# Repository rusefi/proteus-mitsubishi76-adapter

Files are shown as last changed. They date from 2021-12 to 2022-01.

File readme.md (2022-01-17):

https://github.com/rusefi/rusefi and https://github.com/mck1117/proteus

76 pin

2 gen DSM
1995-1999 Mitsubishi Eclipse and Eagle Talon Turbo DSM ECU Pinouts 

v6

Lancer up to 2005?

Our document, need work
[Connector Pinout Spreadsheet, with links to wiring drawings](https://docs.google.com/spreadsheets/d/1ZlcC5cdCwjYoV-z49MNaa9zpLiu_ZYBIx5H-j0F6QpI)

Norman notes https://docs.google.com/spreadsheets/d/1ddxDElQDG0ZjSaX5fpkFeflPWwk7OCHC93gru9Ey_9U

Random sources of info

https://my.prostreetonline.com/2013/09/05/faq-1g-and-2g-dsm-ecu-pinouts/

http://www.stealth316.com/2-ecu-terminals.htm

Compatible case:

MD329098

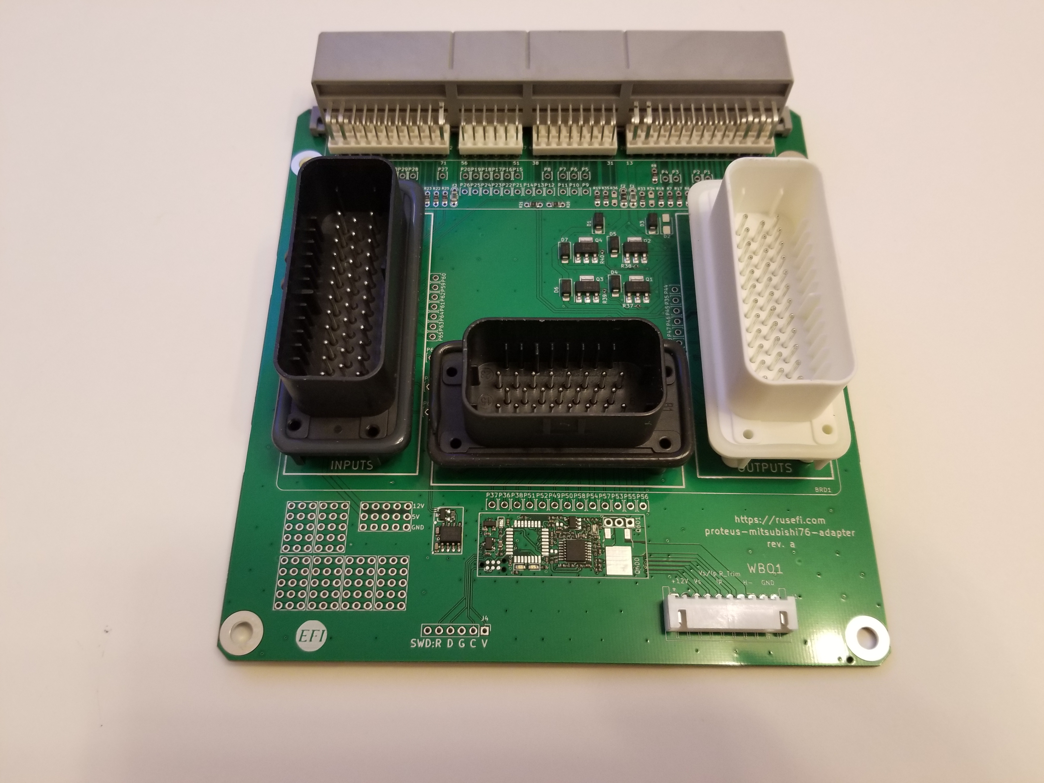
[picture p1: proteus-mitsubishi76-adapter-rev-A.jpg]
x


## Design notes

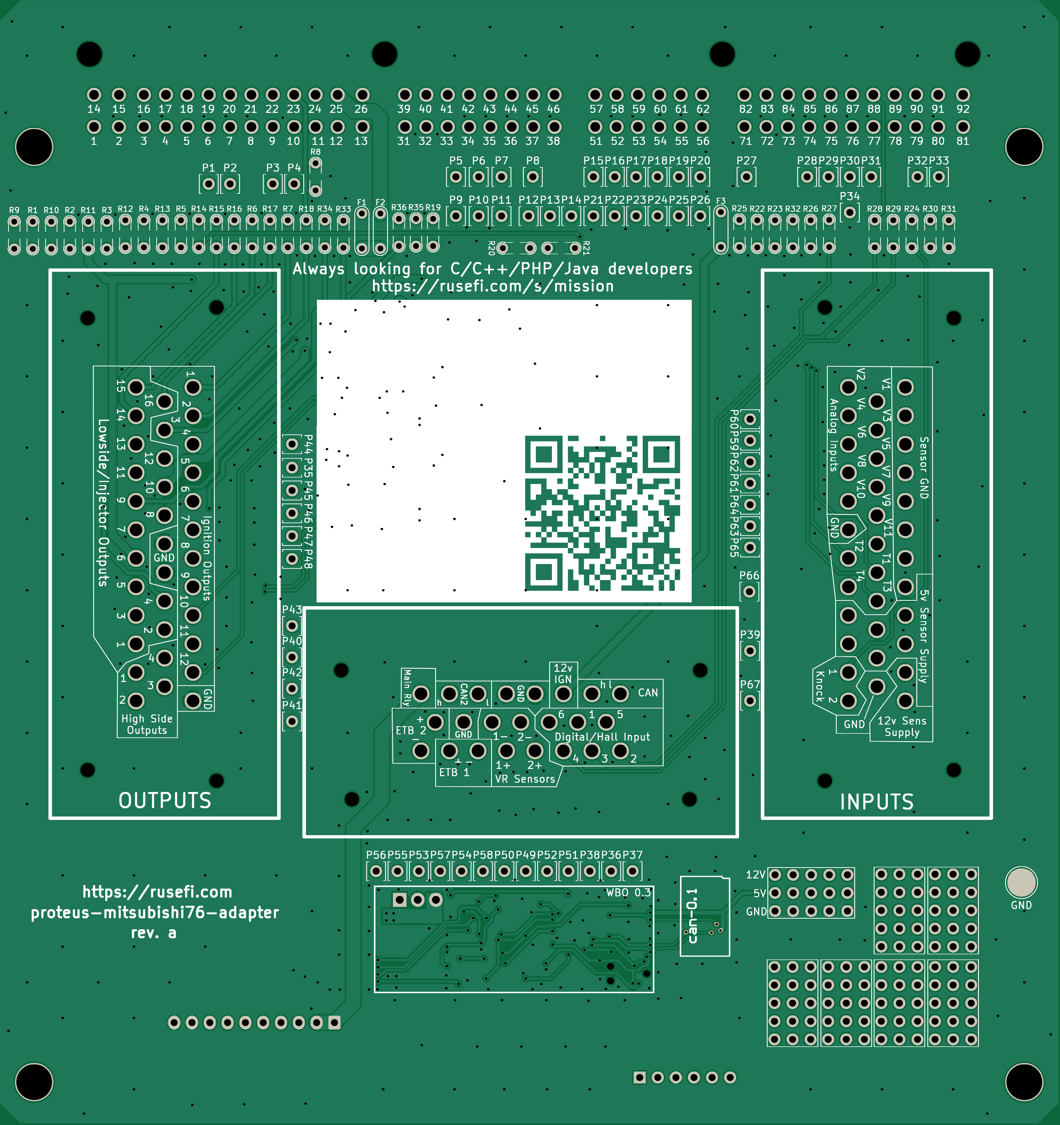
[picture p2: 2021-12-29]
proteus-mitsubishi76-adapter/boards/proteus-mitsubishi76-adapter-a/board/misc/proteus-mitsubishi76-adapter-a-bottom.png

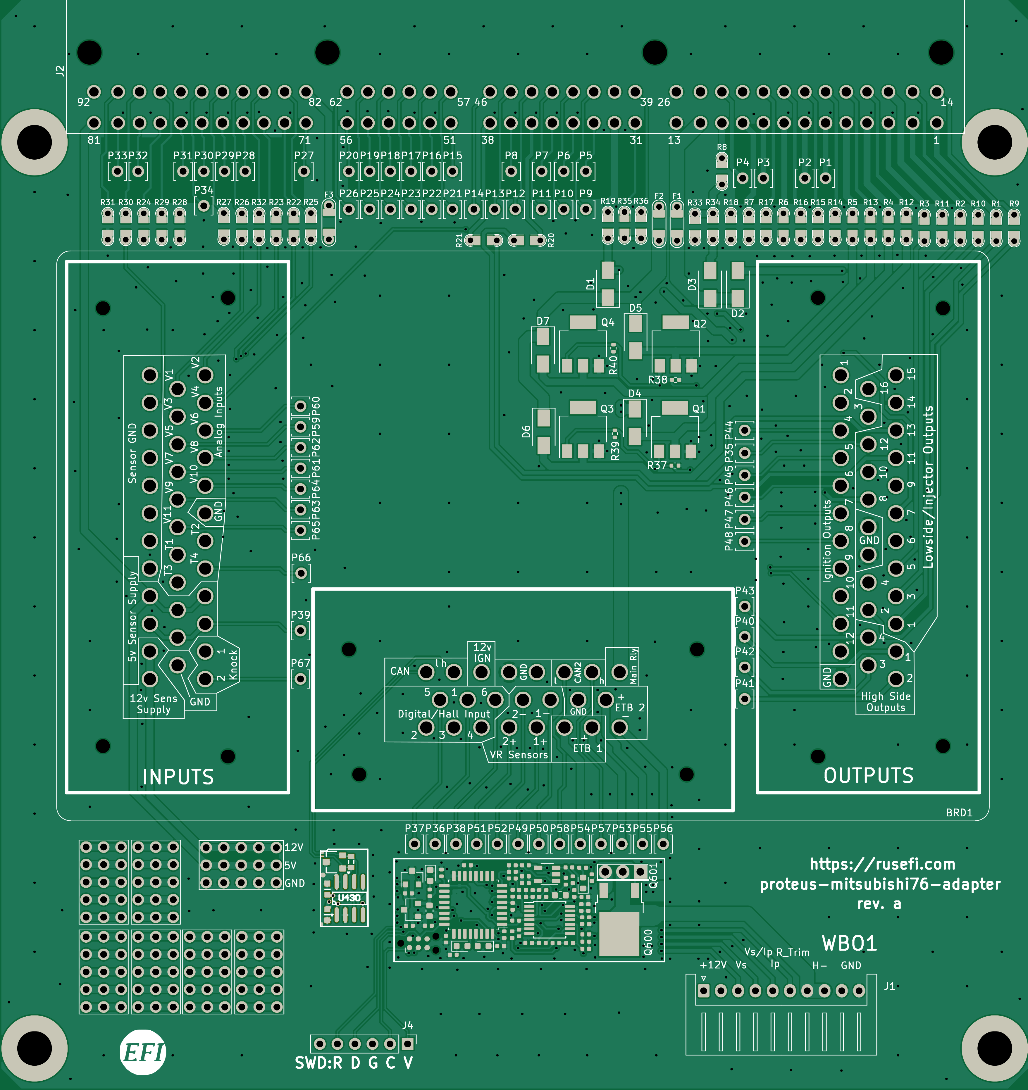
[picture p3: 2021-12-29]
proteus-mitsubishi76-adapter/boards/proteus-mitsubishi76-adapter-a/board/misc/proteus-mitsubishi76-adapter-a-top.png

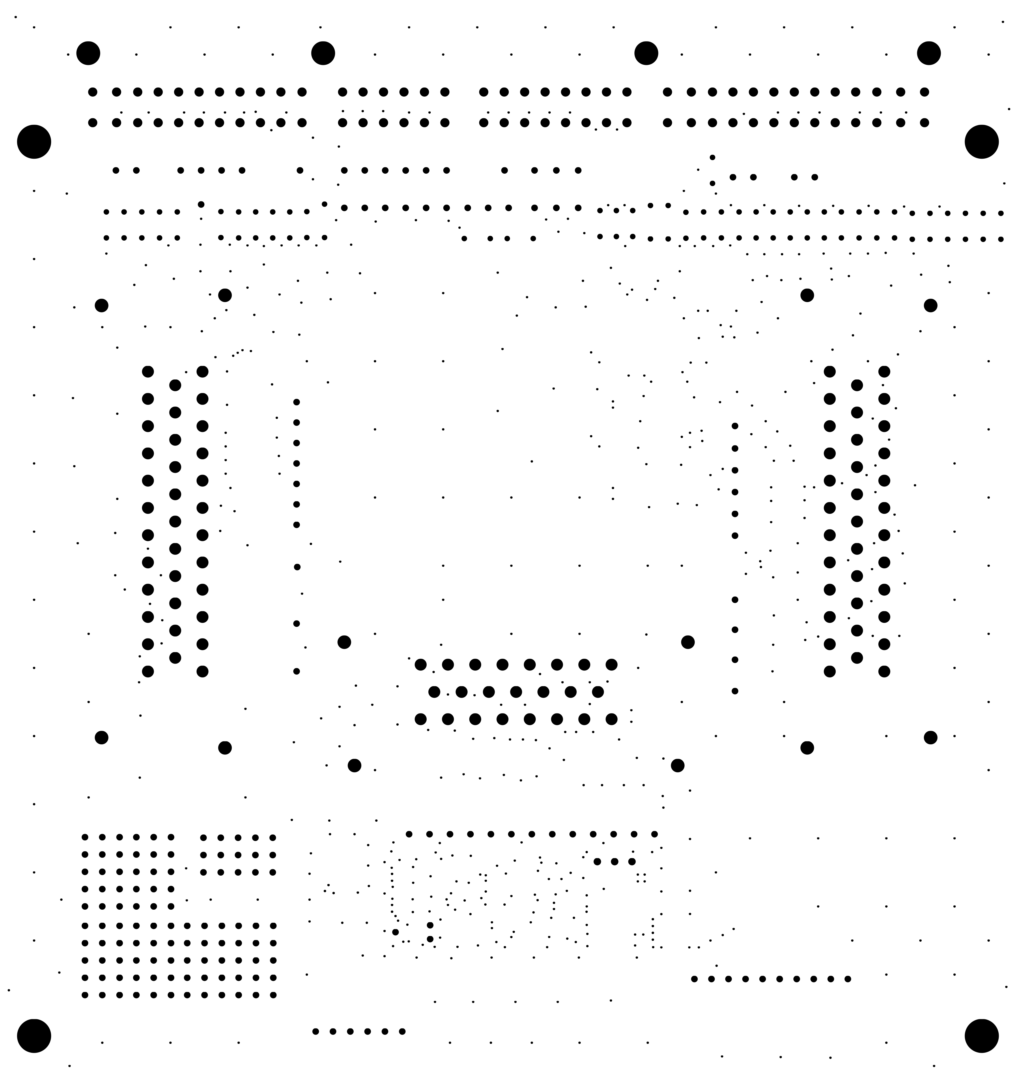
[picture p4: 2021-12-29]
proteus-mitsubishi76-adapter/boards/proteus-mitsubishi76-adapter-a/board/misc/proteus-mitsubishi76-adapter-a-outline.png

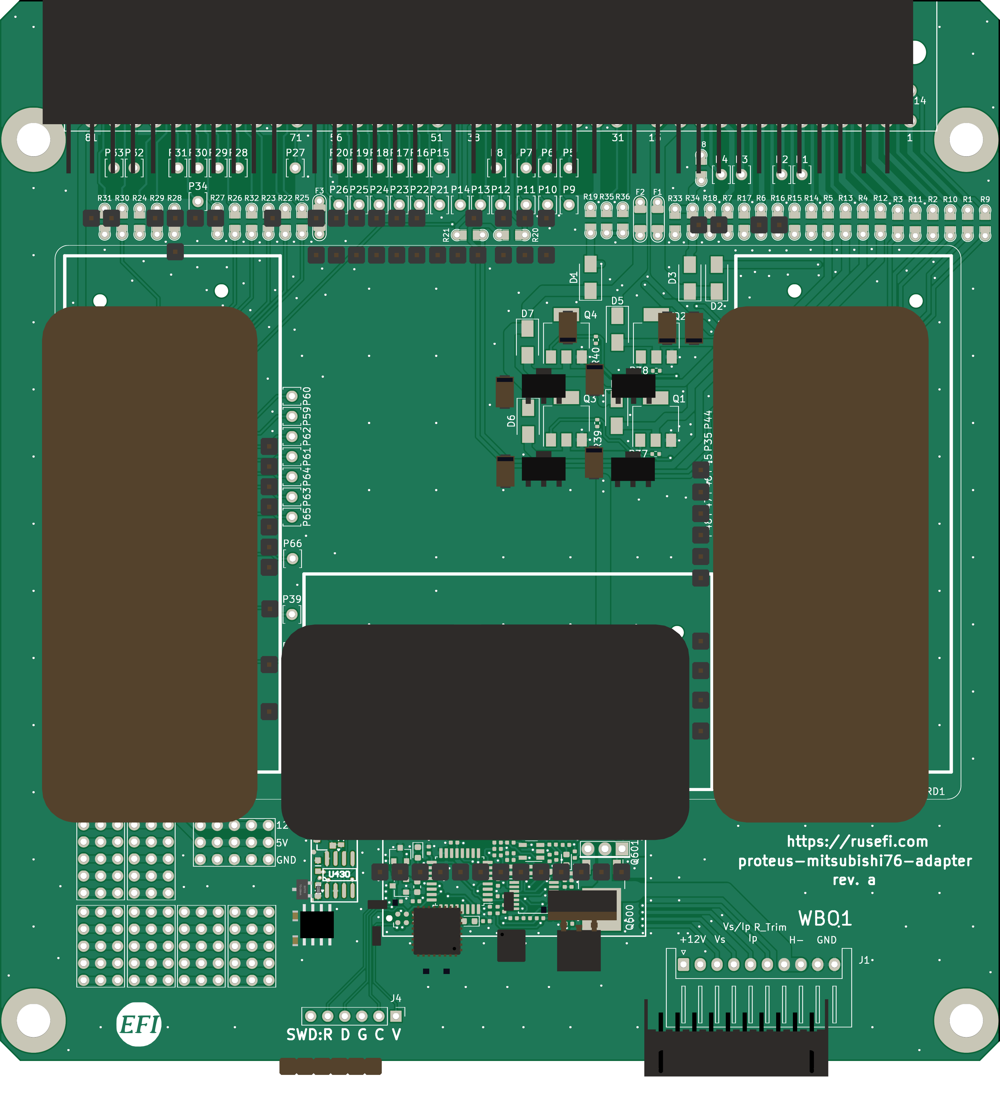
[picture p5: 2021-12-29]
proteus-mitsubishi76-adapter/boards/proteus-mitsubishi76-adapter-a/board/proteus-mitsubishi76-adapter-a.png

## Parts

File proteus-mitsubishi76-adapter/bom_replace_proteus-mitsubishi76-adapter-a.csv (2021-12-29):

#WBO low-side (D2PAK, TO220)
Q600,
Q601,
#WBO STM32
U602,
#low-side
Q1,"BSP78","SOT-223","C56914"
Q2,"BSP78","SOT-223","C56914"
Q3,"BSP78","SOT-223","C56914"
Q4,"BSP78","SOT-223","C56914"

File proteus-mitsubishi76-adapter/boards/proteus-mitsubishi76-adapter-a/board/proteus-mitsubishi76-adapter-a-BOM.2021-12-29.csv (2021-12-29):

Comment | Designator | Footprint | LCSC Part #
proteus | BRD1 | proteus
D_Schottky | D1, D3, D4, D5, D6, D7 | D_SMA | C8678
DNP | D2 | D_SMA
Fuse-Pad-Pad | F1, F3 | PAD-1206-PAD | C182446
Fuse-Pad-Pad | F2 | PAD-1206-PAD
RUSEFI_LOGO | G1 | rusefi_logo
PROTO_AREA | G2 | PROTO_AREA
PROTO_AREA | G3 | PROTO_AREA
PROTO_AREA | G4 | PROTO_AREA
PROTO_AREA | G5 | PROTO_AREA
PROTO_AREA | G6 | PROTO_AREA
PROTO_AREA | G7 | PROTO_AREA
PROTO_AREA | G8 | PROTO_AREA
MountingHole | H1 | MountingHole_5mm_Pad_TopOnly
MountingHole | H2 | MountingHole_5mm_Pad_TopOnly
MountingHole | H3 | MountingHole_5mm_Pad_TopOnly
MountingHole | H4 | MountingHole_5mm_Pad_TopOnly
XH-10AW | J1 | JST_XH_S10B-XH-A_1x10_P2.50mm_Horizontal | C14652
TE-3-178780-6 | J2 | TE-3-178780-6
Conn_01x06 | J4 | PinHeader_1x06_P2.54mm_Vertical
Conn_01x01 | J5 | TestPoint_Pad_D4.0mm
Pad | P1 | PAD-TH
Pad | P2 | PAD-TH
Pad | P3 | PAD-TH
Pad | P4 | PAD-TH
Pad | P5 | PAD-TH
Pad | P6 | PAD-TH
Pad | P7 | PAD-TH
Pad | P8 | PAD-TH
Pad | P9 | PAD-TH
Pad | P10 | PAD-TH
Pad | P11 | PAD-TH
Pad | P12 | PAD-TH
Pad | P13 | PAD-TH
Pad | P14 | PAD-TH
Pad | P15 | PAD-TH
Pad | P16 | PAD-TH
Pad | P17 | PAD-TH
Pad | P18 | PAD-TH
Pad | P19 | PAD-TH
Pad | P20 | PAD-TH
Pad | P21 | PAD-TH
Pad | P22 | PAD-TH
Pad | P23 | PAD-TH
Pad | P24 | PAD-TH
Pad | P25 | PAD-TH
Pad | P26 | PAD-TH
Pad | P27 | PAD-TH
Pad | P28 | PAD-TH
Pad | P29 | PAD-TH
Pad | P30 | PAD-TH
Pad | P31 | PAD-TH
Pad | P32 | PAD-TH
Pad | P33 | PAD-TH
Pad | P34 | PAD-TH
Pad | P35 | PAD-TH
Pad | P36 | PAD-TH
Pad | P37 | PAD-TH
Pad | P38 | PAD-TH
Pad | P39 | PAD-TH
Pad | P40 | PAD-TH
Pad | P41 | PAD-TH
Pad | P42 | PAD-TH
Pad | P43 | PAD-TH
Pad | P44 | PAD-TH
Pad | P45 | PAD-TH
Pad | P46 | PAD-TH
Pad | P47 | PAD-TH
Pad | P48 | PAD-TH
Pad | P49 | PAD-TH
Pad | P50 | PAD-TH
Pad | P51 | PAD-TH
Pad | P52 | PAD-TH
Pad | P53 | PAD-TH
Pad | P54 | PAD-TH
Pad | P55 | PAD-TH
Pad | P56 | PAD-TH
Pad | P57 | PAD-TH
Pad | P58 | PAD-TH
Pad | P59 | PAD-TH
Pad | P60 | PAD-TH
Pad | P61 | PAD-TH
Pad | P62 | PAD-TH
Pad | P63 | PAD-TH
Pad | P64 | PAD-TH
Pad | P65 | PAD-TH
Pad | P66 | PAD-TH
Pad | P67 | PAD-TH
Jumper-Pad-Pad | R1, R2, R3, R4, R5, R6, R7, R8, R9, R10, R11, R12, R13, R14, R15, R16, R17, R18, R19, R20, R21, R22, R23, R24, R25, R26, R27, R28, R29, R30, R31, R32, R33, R35 | PAD-0805-PAD | C17477
Jumper-Pad-Pad | R34 | PAD-0805-PAD
Jumper-Pad-Pad | R36 | PAD-0805-PAD
10k | R37, R38, R39, R40 | R0402 | C60489
1u | C600, C607, C609, C610, C611 | C0402 | C52923
100n | C601, C602, C605, C608, C612, C613, C614, C615 | C0402 | C1525
33n | C603 | C0402 | C1585
DNP | C604 | C0402
DNP | C606 | C0402
4.7u | C616 | C0603 | C19666
LED-RED-0603 | D600, D603 | LED-0603 | C2286
LED-GREEN-0603 | D601 | LED-0603 | C72043
LED-BLUE-0603 | D602 | LED-0603 | C72041
1k | R600, R601, R616, R617, R622, R626, R627, R628 | R0402 | C11702
68k | R602, R603 | R0402 | C36871
10k | R604, R605, R613, R614, R618, R619, R625 | R0402 | C25744
10 | R606 | R0402 | C25077
22k | R607 | R0402 | C25768
47 | R608 | R0402 | C25118
61.9 | R609 | R0603 | C23092
20k | R610, R611, R612 | R0402 | C25765
100k | R615, R621 | R0402 | C25741
27k | R620, R623 | R0402 | C25771
3.3k | R624 | R0402 | C25890
MCP6004 | U600 | TSSOP14 | C50282
AD8628 | U601 | TSOT23-5 | C29309
REF3033 | U603 | SOT-23 | C36658
XC6206P332MR | U604 | SOT-23 | C5446
100n | C430, C431 | C0603 | C14663
PESD1CAN | D430 | SOT-23 | C343993
120 | R430 | R0603 | C22787
TJA1051T/3/1J | U430 | SO8 | C38695
BSP78 | Q1, Q2, Q3, Q4 | SOT-223 | C56914

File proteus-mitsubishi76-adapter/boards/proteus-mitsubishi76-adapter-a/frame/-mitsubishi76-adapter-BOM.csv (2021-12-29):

Comment | Designator | Footprint | LCSC Part #
proteus | BRD1 | proteus
D_Schottky | D1 | D_SMA | C8678
DNP | D2 | D_SMA
D_Schottky | D3 | D_SMA | C8678
D_Schottky | D4 | D_SMA | C8678
D_Schottky | D5 | D_SMA | C8678
D_Schottky | D6 | D_SMA | C8678
D_Schottky | D7 | D_SMA | C8678
Fuse-Pad-Pad | F1 | PAD-1206-PAD | C182446
Fuse-Pad-Pad | F2 | PAD-1206-PAD
Fuse-Pad-Pad | F3 | PAD-1206-PAD | C182446
RUSEFI_LOGO | G1 | rusefi_logo
PROTO_AREA | G2 | PROTO_AREA
PROTO_AREA | G3 | PROTO_AREA
PROTO_AREA | G4 | PROTO_AREA
PROTO_AREA | G5 | PROTO_AREA
PROTO_AREA | G6 | PROTO_AREA
PROTO_AREA | G7 | PROTO_AREA
PROTO_AREA | G8 | PROTO_AREA
MountingHole | H1 | MountingHole_5mm_Pad_TopOnly
MountingHole | H2 | MountingHole_5mm_Pad_TopOnly
MountingHole | H3 | MountingHole_5mm_Pad_TopOnly
MountingHole | H4 | MountingHole_5mm_Pad_TopOnly
XH-10AW | J1 | JST_XH_S10B-XH-A_1x10_P2.50mm_Horizontal | C14652
TE-3-178780-6 | J2 | TE-3-178780-6
Conn_01x06 | J4 | PinHeader_1x06_P2.54mm_Vertical
Conn_01x01 | J5 | TestPoint_Pad_D4.0mm
Module:wbo/0.3 | M1 | wbo
Module:can/0.1 | M2 | can
Pad | P1 | PAD-TH
Pad | P2 | PAD-TH
Pad | P3 | PAD-TH
Pad | P4 | PAD-TH
Pad | P5 | PAD-TH
Pad | P6 | PAD-TH
Pad | P7 | PAD-TH
Pad | P8 | PAD-TH
Pad | P9 | PAD-TH
Pad | P10 | PAD-TH
Pad | P11 | PAD-TH
Pad | P12 | PAD-TH
Pad | P13 | PAD-TH
Pad | P14 | PAD-TH
Pad | P15 | PAD-TH
Pad | P16 | PAD-TH
Pad | P17 | PAD-TH
Pad | P18 | PAD-TH
Pad | P19 | PAD-TH
Pad | P20 | PAD-TH
Pad | P21 | PAD-TH
Pad | P22 | PAD-TH
Pad | P23 | PAD-TH
Pad | P24 | PAD-TH
Pad | P25 | PAD-TH
Pad | P26 | PAD-TH
Pad | P27 | PAD-TH
Pad | P28 | PAD-TH
Pad | P29 | PAD-TH
Pad | P30 | PAD-TH
Pad | P31 | PAD-TH
Pad | P32 | PAD-TH
Pad | P33 | PAD-TH
Pad | P34 | PAD-TH
Pad | P35 | PAD-TH
Pad | P36 | PAD-TH
Pad | P37 | PAD-TH
Pad | P38 | PAD-TH
Pad | P39 | PAD-TH
Pad | P40 | PAD-TH
Pad | P41 | PAD-TH
Pad | P42 | PAD-TH
Pad | P43 | PAD-TH
Pad | P44 | PAD-TH
Pad | P45 | PAD-TH
Pad | P46 | PAD-TH
Pad | P47 | PAD-TH
Pad | P48 | PAD-TH
Pad | P49 | PAD-TH
Pad | P50 | PAD-TH
Pad | P51 | PAD-TH
Pad | P52 | PAD-TH
Pad | P53 | PAD-TH
Pad | P54 | PAD-TH
Pad | P55 | PAD-TH
Pad | P56 | PAD-TH
Pad | P57 | PAD-TH
Pad | P58 | PAD-TH
Pad | P59 | PAD-TH
Pad | P60 | PAD-TH
Pad | P61 | PAD-TH
Pad | P62 | PAD-TH
Pad | P63 | PAD-TH
Pad | P64 | PAD-TH
Pad | P65 | PAD-TH
Pad | P66 | PAD-TH
Pad | P67 | PAD-TH
AUIPS2041LTR | Q1 | SOT-223 | C113610
AUIPS2041LTR | Q2 | SOT-223 | C113610
AUIPS2041LTR | Q3 | SOT-223 | C113610
AUIPS2041LTR | Q4 | SOT-223 | C113610
Jumper-Pad-Pad | R1 | PAD-0805-PAD | C17477
Jumper-Pad-Pad | R2 | PAD-0805-PAD | C17477
Jumper-Pad-Pad | R3 | PAD-0805-PAD | C17477
Jumper-Pad-Pad | R4 | PAD-0805-PAD | C17477
Jumper-Pad-Pad | R5 | PAD-0805-PAD | C17477
Jumper-Pad-Pad | R6 | PAD-0805-PAD | C17477
Jumper-Pad-Pad | R7 | PAD-0805-PAD | C17477
Jumper-Pad-Pad | R8 | PAD-0805-PAD | C17477
Jumper-Pad-Pad | R9 | PAD-0805-PAD | C17477
Jumper-Pad-Pad | R10 | PAD-0805-PAD | C17477
Jumper-Pad-Pad | R11 | PAD-0805-PAD | C17477
Jumper-Pad-Pad | R12 | PAD-0805-PAD | C17477
Jumper-Pad-Pad | R13 | PAD-0805-PAD | C17477
Jumper-Pad-Pad | R14 | PAD-0805-PAD | C17477
Jumper-Pad-Pad | R15 | PAD-0805-PAD | C17477
Jumper-Pad-Pad | R16 | PAD-0805-PAD | C17477
Jumper-Pad-Pad | R17 | PAD-0805-PAD | C17477
Jumper-Pad-Pad | R18 | PAD-0805-PAD | C17477
Jumper-Pad-Pad | R19 | PAD-0805-PAD | C17477
Jumper-Pad-Pad | R20 | PAD-0805-PAD | C17477
Jumper-Pad-Pad | R21 | PAD-0805-PAD | C17477
Jumper-Pad-Pad | R22 | PAD-0805-PAD | C17477
Jumper-Pad-Pad | R23 | PAD-0805-PAD | C17477
Jumper-Pad-Pad | R24 | PAD-0805-PAD | C17477
Jumper-Pad-Pad | R25 | PAD-0805-PAD | C17477
Jumper-Pad-Pad | R26 | PAD-0805-PAD | C17477
Jumper-Pad-Pad | R27 | PAD-0805-PAD | C17477
Jumper-Pad-Pad | R28 | PAD-0805-PAD | C17477
Jumper-Pad-Pad | R29 | PAD-0805-PAD | C17477
Jumper-Pad-Pad | R30 | PAD-0805-PAD | C17477
Jumper-Pad-Pad | R31 | PAD-0805-PAD | C17477
Jumper-Pad-Pad | R32 | PAD-0805-PAD | C17477
Jumper-Pad-Pad | R33 | PAD-0805-PAD | C17477
Jumper-Pad-Pad | R34 | PAD-0805-PAD
Jumper-Pad-Pad | R35 | PAD-0805-PAD | C17477
Jumper-Pad-Pad | R36 | PAD-0805-PAD
10k | R37 | R0402 | C60489
10k | R38 | R0402 | C60489
10k | R39 | R0402 | C60489
10k | R40 | R0402 | C60489

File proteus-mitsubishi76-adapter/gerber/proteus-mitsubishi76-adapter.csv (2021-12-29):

Comment | Designator | Footprint | LCSC Part #
proteus | BRD1 | kicad6-libraries:proteus
D_Schottky | D1 | Diode_SMD:D_SMA | C8678
DNP | D2 | Diode_SMD:D_SMA
D_Schottky | D3 | Diode_SMD:D_SMA | C8678
D_Schottky | D4 | Diode_SMD:D_SMA | C8678
D_Schottky | D5 | Diode_SMD:D_SMA | C8678
D_Schottky | D6 | Diode_SMD:D_SMA | C8678
D_Schottky | D7 | Diode_SMD:D_SMA | C8678
Fuse-Pad-Pad | F1 | hellen-one-common:PAD-1206-PAD | C182446
Fuse-Pad-Pad | F2 | hellen-one-common:PAD-1206-PAD
Fuse-Pad-Pad | F3 | hellen-one-common:PAD-1206-PAD | C182446
RUSEFI_LOGO | G1 | kicad6-libraries:rusefi_logo
PROTO_AREA | G2 | hellen-one-common:PROTO_AREA
PROTO_AREA | G3 | hellen-one-common:PROTO_AREA
PROTO_AREA | G4 | hellen-one-common:PROTO_AREA
PROTO_AREA | G5 | hellen-one-common:PROTO_AREA
PROTO_AREA | G6 | hellen-one-common:PROTO_AREA
PROTO_AREA | G7 | hellen-one-common:PROTO_AREA
PROTO_AREA | G8 | hellen-one-common:PROTO_AREA
MountingHole | H1 | MountingHole:MountingHole_5mm_Pad_TopOnly
MountingHole | H2 | MountingHole:MountingHole_5mm_Pad_TopOnly
MountingHole | H3 | MountingHole:MountingHole_5mm_Pad_TopOnly
MountingHole | H4 | MountingHole:MountingHole_5mm_Pad_TopOnly
XH-10AW | J1 | Connector_JST:JST_XH_S10B-XH-A_1x10_P2.50mm_Horizontal | C14652
TE-3-178780-6 | J2 | kicad6-libraries:TE-3-178780-6
Conn_01x06 | J4 | Connector_PinHeader_2.54mm:PinHeader_1x06_P2.54mm_Vertical
Conn_01x01 | J5 | TestPoint:TestPoint_Pad_D4.0mm
Module-wbo-0.3 | M1 | hellen-one-wbo-0.3:wbo
Module-can-0.1 | M2 | hellen-one-can-0.1:can
Pad | P1 | hellen-one-common:PAD-TH
Pad | P2 | hellen-one-common:PAD-TH
Pad | P3 | hellen-one-common:PAD-TH
Pad | P4 | hellen-one-common:PAD-TH
Pad | P5 | hellen-one-common:PAD-TH
Pad | P6 | hellen-one-common:PAD-TH
Pad | P7 | hellen-one-common:PAD-TH
Pad | P8 | hellen-one-common:PAD-TH
Pad | P9 | hellen-one-common:PAD-TH
Pad | P10 | hellen-one-common:PAD-TH
Pad | P11 | hellen-one-common:PAD-TH
Pad | P12 | hellen-one-common:PAD-TH
Pad | P13 | hellen-one-common:PAD-TH
Pad | P14 | hellen-one-common:PAD-TH
Pad | P15 | hellen-one-common:PAD-TH
Pad | P16 | hellen-one-common:PAD-TH
Pad | P17 | hellen-one-common:PAD-TH
Pad | P18 | hellen-one-common:PAD-TH
Pad | P19 | hellen-one-common:PAD-TH
Pad | P20 | hellen-one-common:PAD-TH
Pad | P21 | hellen-one-common:PAD-TH
Pad | P22 | hellen-one-common:PAD-TH
Pad | P23 | hellen-one-common:PAD-TH
Pad | P24 | hellen-one-common:PAD-TH
Pad | P25 | hellen-one-common:PAD-TH
Pad | P26 | hellen-one-common:PAD-TH
Pad | P27 | hellen-one-common:PAD-TH
Pad | P28 | hellen-one-common:PAD-TH
Pad | P29 | hellen-one-common:PAD-TH
Pad | P30 | hellen-one-common:PAD-TH
Pad | P31 | hellen-one-common:PAD-TH
Pad | P32 | hellen-one-common:PAD-TH
Pad | P33 | hellen-one-common:PAD-TH
Pad | P34 | hellen-one-common:PAD-TH
Pad | P35 | hellen-one-common:PAD-TH
Pad | P36 | hellen-one-common:PAD-TH
Pad | P37 | hellen-one-common:PAD-TH
Pad | P38 | hellen-one-common:PAD-TH
Pad | P39 | hellen-one-common:PAD-TH
Pad | P40 | hellen-one-common:PAD-TH
Pad | P41 | hellen-one-common:PAD-TH
Pad | P42 | hellen-one-common:PAD-TH
Pad | P43 | hellen-one-common:PAD-TH
Pad | P44 | hellen-one-common:PAD-TH
Pad | P45 | hellen-one-common:PAD-TH
Pad | P46 | hellen-one-common:PAD-TH
Pad | P47 | hellen-one-common:PAD-TH
Pad | P48 | hellen-one-common:PAD-TH
Pad | P49 | hellen-one-common:PAD-TH
Pad | P50 | hellen-one-common:PAD-TH
Pad | P51 | hellen-one-common:PAD-TH
Pad | P52 | hellen-one-common:PAD-TH
Pad | P53 | hellen-one-common:PAD-TH
Pad | P54 | hellen-one-common:PAD-TH
Pad | P55 | hellen-one-common:PAD-TH
Pad | P56 | hellen-one-common:PAD-TH
Pad | P57 | hellen-one-common:PAD-TH
Pad | P58 | hellen-one-common:PAD-TH
Pad | P59 | hellen-one-common:PAD-TH
Pad | P60 | hellen-one-common:PAD-TH
Pad | P61 | hellen-one-common:PAD-TH
Pad | P62 | hellen-one-common:PAD-TH
Pad | P63 | hellen-one-common:PAD-TH
Pad | P64 | hellen-one-common:PAD-TH
Pad | P65 | hellen-one-common:PAD-TH
Pad | P66 | hellen-one-common:PAD-TH
Pad | P67 | hellen-one-common:PAD-TH
AUIPS2041LTR | Q1 | Package_TO_SOT_SMD:SOT-223 | C113610
AUIPS2041LTR | Q2 | Package_TO_SOT_SMD:SOT-223 | C113610
AUIPS2041LTR | Q3 | Package_TO_SOT_SMD:SOT-223 | C113610
AUIPS2041LTR | Q4 | Package_TO_SOT_SMD:SOT-223 | C113610
Jumper-Pad-Pad | R1 | hellen-one-common:PAD-0805-PAD | C17477
Jumper-Pad-Pad | R2 | hellen-one-common:PAD-0805-PAD | C17477
Jumper-Pad-Pad | R3 | hellen-one-common:PAD-0805-PAD | C17477
Jumper-Pad-Pad | R4 | hellen-one-common:PAD-0805-PAD | C17477
Jumper-Pad-Pad | R5 | hellen-one-common:PAD-0805-PAD | C17477
Jumper-Pad-Pad | R6 | hellen-one-common:PAD-0805-PAD | C17477
Jumper-Pad-Pad | R7 | hellen-one-common:PAD-0805-PAD | C17477
Jumper-Pad-Pad | R8 | hellen-one-common:PAD-0805-PAD | C17477
Jumper-Pad-Pad | R9 | hellen-one-common:PAD-0805-PAD | C17477
Jumper-Pad-Pad | R10 | hellen-one-common:PAD-0805-PAD | C17477
Jumper-Pad-Pad | R11 | hellen-one-common:PAD-0805-PAD | C17477
Jumper-Pad-Pad | R12 | hellen-one-common:PAD-0805-PAD | C17477
Jumper-Pad-Pad | R13 | hellen-one-common:PAD-0805-PAD | C17477
Jumper-Pad-Pad | R14 | hellen-one-common:PAD-0805-PAD | C17477
Jumper-Pad-Pad | R15 | hellen-one-common:PAD-0805-PAD | C17477
Jumper-Pad-Pad | R16 | hellen-one-common:PAD-0805-PAD | C17477
Jumper-Pad-Pad | R17 | hellen-one-common:PAD-0805-PAD | C17477
Jumper-Pad-Pad | R18 | hellen-one-common:PAD-0805-PAD | C17477
Jumper-Pad-Pad | R19 | hellen-one-common:PAD-0805-PAD | C17477
Jumper-Pad-Pad | R20 | hellen-one-common:PAD-0805-PAD | C17477
Jumper-Pad-Pad | R21 | hellen-one-common:PAD-0805-PAD | C17477
Jumper-Pad-Pad | R22 | hellen-one-common:PAD-0805-PAD | C17477
Jumper-Pad-Pad | R23 | hellen-one-common:PAD-0805-PAD | C17477
Jumper-Pad-Pad | R24 | hellen-one-common:PAD-0805-PAD | C17477
Jumper-Pad-Pad | R25 | hellen-one-common:PAD-0805-PAD | C17477
Jumper-Pad-Pad | R26 | hellen-one-common:PAD-0805-PAD | C17477
Jumper-Pad-Pad | R27 | hellen-one-common:PAD-0805-PAD | C17477
Jumper-Pad-Pad | R28 | hellen-one-common:PAD-0805-PAD | C17477
Jumper-Pad-Pad | R29 | hellen-one-common:PAD-0805-PAD | C17477
Jumper-Pad-Pad | R30 | hellen-one-common:PAD-0805-PAD | C17477
Jumper-Pad-Pad | R31 | hellen-one-common:PAD-0805-PAD | C17477
Jumper-Pad-Pad | R32 | hellen-one-common:PAD-0805-PAD | C17477
Jumper-Pad-Pad | R33 | hellen-one-common:PAD-0805-PAD | C17477
Jumper-Pad-Pad | R34 | hellen-one-common:PAD-0805-PAD
Jumper-Pad-Pad | R35 | hellen-one-common:PAD-0805-PAD | C17477
Jumper-Pad-Pad | R36 | hellen-one-common:PAD-0805-PAD
10k | R37 | Resistor_SMD:R_0402_1005Metric | C60489
10k | R38 | Resistor_SMD:R_0402_1005Metric | C60489
10k | R39 | Resistor_SMD:R_0402_1005Metric | C60489
10k | R40 | Resistor_SMD:R_0402_1005Metric | C60489

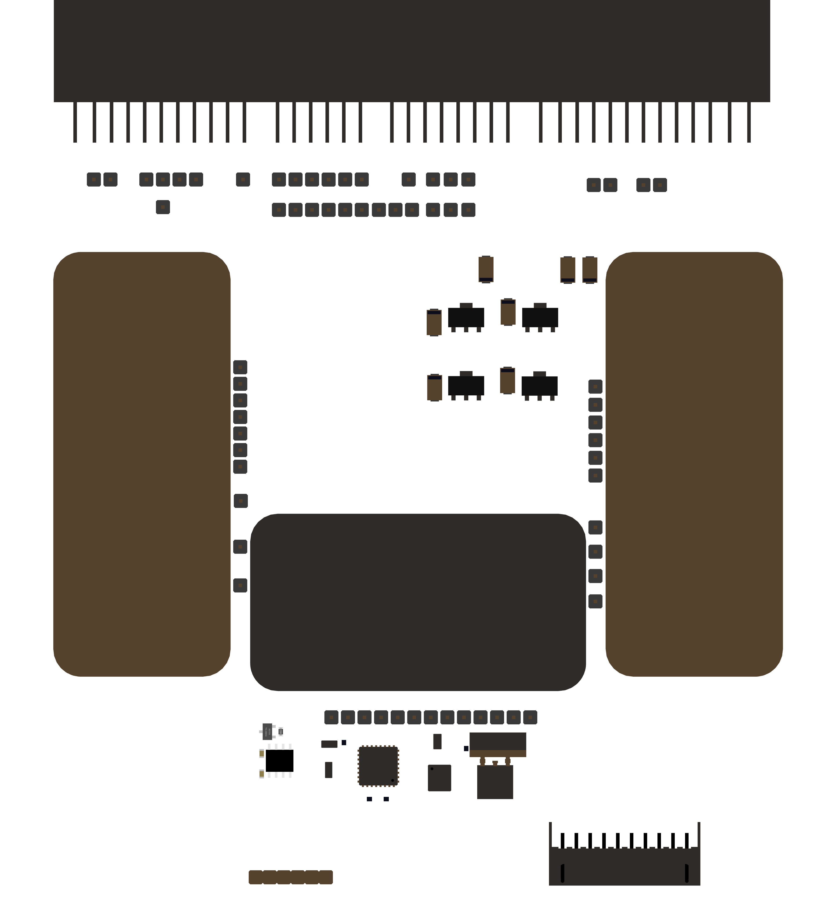
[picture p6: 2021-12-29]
proteus-mitsubishi76-adapter/boards/proteus-mitsubishi76-adapter-a/board/misc/proteus-mitsubishi76-adapter-a-components.png

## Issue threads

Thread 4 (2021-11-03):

Idle stepper plan for Proteus

rusefillc, 2021-11-03:
I have six pin stepper idle

40 OHm between middle +12 wires and other ends of 80 OHm coils. Coils A and B seem to NOT be connecter.

My preference would be to use two Proteus H-bridges. What do I do with the middle +12?

What do I do about those being connected on the vehicle? would H-bridge plan not work until +12 middle pins are disconnected?

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

full schematics https://github.com/rusefi/rusefi/wiki/Vault-of-Mitsubishi#1995-3000gt

rusefillc, 2021-11-03:
@andreika-git @mck1117 ^^^

mck1117, 2021-11-03:
that's a unipolar stepper, not a bipolar stepper, so it needs yet another different control mode, and four lowside outputs

mck1117, 2021-11-03:
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

rusefillc, 2021-11-03:
Would cutting those +12v wires make it a bipolar stepper?

mck1117, 2021-11-08:
It may work, but it's not very PnP. It's possible the motor may be too weak if we rewired it as a bipolar stepper.

rusefillc, 2021-11-14:
So we use four low sides for stepper coils great news we have those on Proteus

@mck1117 do we need fly-backs on those lines?

rusefillc, 2021-12-05:
Let's see if we have enough Proteus low sides, let's add fly-backs on the board just in case.

Qwerty-OFF, 2021-12-08:
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

rusefillc, 2021-12-09:
@mck1117 does this look right?

mck1117, 2021-12-09:
looks fine to me

Closed 2021-12-08.

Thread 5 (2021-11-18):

pin conflicts table

rusefillc, 2021-11-18:
http://www.stealth316.com/2-ecu-terminals.htm all the way at the bottom has

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

do we have enough schematics to comprehend/confirm all the pins on that table?

ElDominio, 2021-12-06:
https://www.aemelectronics.com/files/instructions/30-6311%20Series%202%20Plug%20&%20Play%20EMS.pdf this is what I typically use

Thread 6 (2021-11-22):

Pin 71 question starting system

rusefillc, 2021-11-22:

rusefillc, 2021-12-04:
See bottom of https://github.com/rusefi/rusefi/wiki/1995-3000gt

rusefillc, 2021-12-05:
@ElDominio any idea what is pin 71? is it starter feedback into ECU which we do not care about?

ElDominio, 2021-12-06:
From what I can remember, if you send 12v, the car cranks on that pin. Still works with the normal key even without an ECU present

rusefillc, 2021-12-08:
So we just have a via and move on

Closed 2021-12-08.

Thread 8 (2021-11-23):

coil control level

rusefillc, 2021-11-23:
5v or 12v or else?

rusefillc, 2021-11-23:
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

rusefillc, 2021-12-04:
@elElDominio what do you think? 5v or 12v?

rusefillc, 2021-12-05:
Let's decide that 5v

ElDominio, 2021-12-05:
It's 5v level

Closed 2021-12-06.

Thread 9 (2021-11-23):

MAF which wire is what

rusefillc, 2021-11-23:
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

rusefillc, 2021-11-23:
https://mitsubishiforum.com/forum/eclipse-frequently-asked-question-section-58/dsm-maf-pinout-15730/ seems to match info we have
pin 5 is clearly GND and some vehicles show intake air

```
2G TURBO MAF

1 â€“ 5V Power supply
2 â€“ Barometric pressure
3 â€“ Air flow sensor
4 â€“ MPI control relay
5 â€“ Ground
6 â€“ Intake air temperature
7 â€“ Volume Air Flow
```

rusefillc, 2021-11-23:
also https://docs.google.com/spreadsheets/d/1ddxDElQDG0ZjSaX5fpkFeflPWwk7OCHC93gru9Ey_9U/ confirms that

Closed 2021-12-06.

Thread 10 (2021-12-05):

Connector and car pins mapping

Qwerty-OFF, 2021-12-05:
From 1 to 72 pins in connector:

TE official drawing

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
and
1-26
31-46
51-62
71-92
on wiring diagrams. The number of contacts shows that these are separate sections of the connector. But how are the pins numbered within the section?

rusefillc, 2021-12-05:
https://my.prostreetonline.com/2013/09/05/faq-1g-and-2g-dsm-ecu-pinouts/ has a good

Closed 2021-12-06.

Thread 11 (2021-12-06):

jdm evo VII ecu the fuel pump pin should be pin 8 instead of pin 22

rusefillc, 2021-12-06:
Maurice says "jdm evo VII ecu the fuel pump pin should be pin 8 instead of pin 22"

ElDominio, 2021-12-06:
some years swap the A/C clutch and fuel pump pins around, for reasons I don't know

rusefillc, 2021-12-06:
@Qwerty-OFF please out a comment next to those pins

Qwerty-OFF, 2021-12-08:
Done
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

Closed 2021-12-08.

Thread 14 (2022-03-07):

VND14NV04  tab not connected?

rusefillc, 2022-03-07:
should VND14NV04 tab be connected somewhere?

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

Qwerty-OFF, 2022-03-09:
This is AUIPS2041LTR, not VND14NV04. In this case tab is not connected for compatibility with other lowside switches.

rusefillc, 2022-03-09:
So for VND14NV04 usage example we have WBO mosfet?

rusefillc, 2022-03-09:
Q600?

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

Closed 2022-03-09.

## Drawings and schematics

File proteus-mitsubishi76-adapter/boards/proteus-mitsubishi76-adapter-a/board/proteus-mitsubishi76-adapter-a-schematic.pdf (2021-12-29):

## R20 P8R19 P6P14

# J2 TE-3-178780-6 P3R5 P11 P18 P15

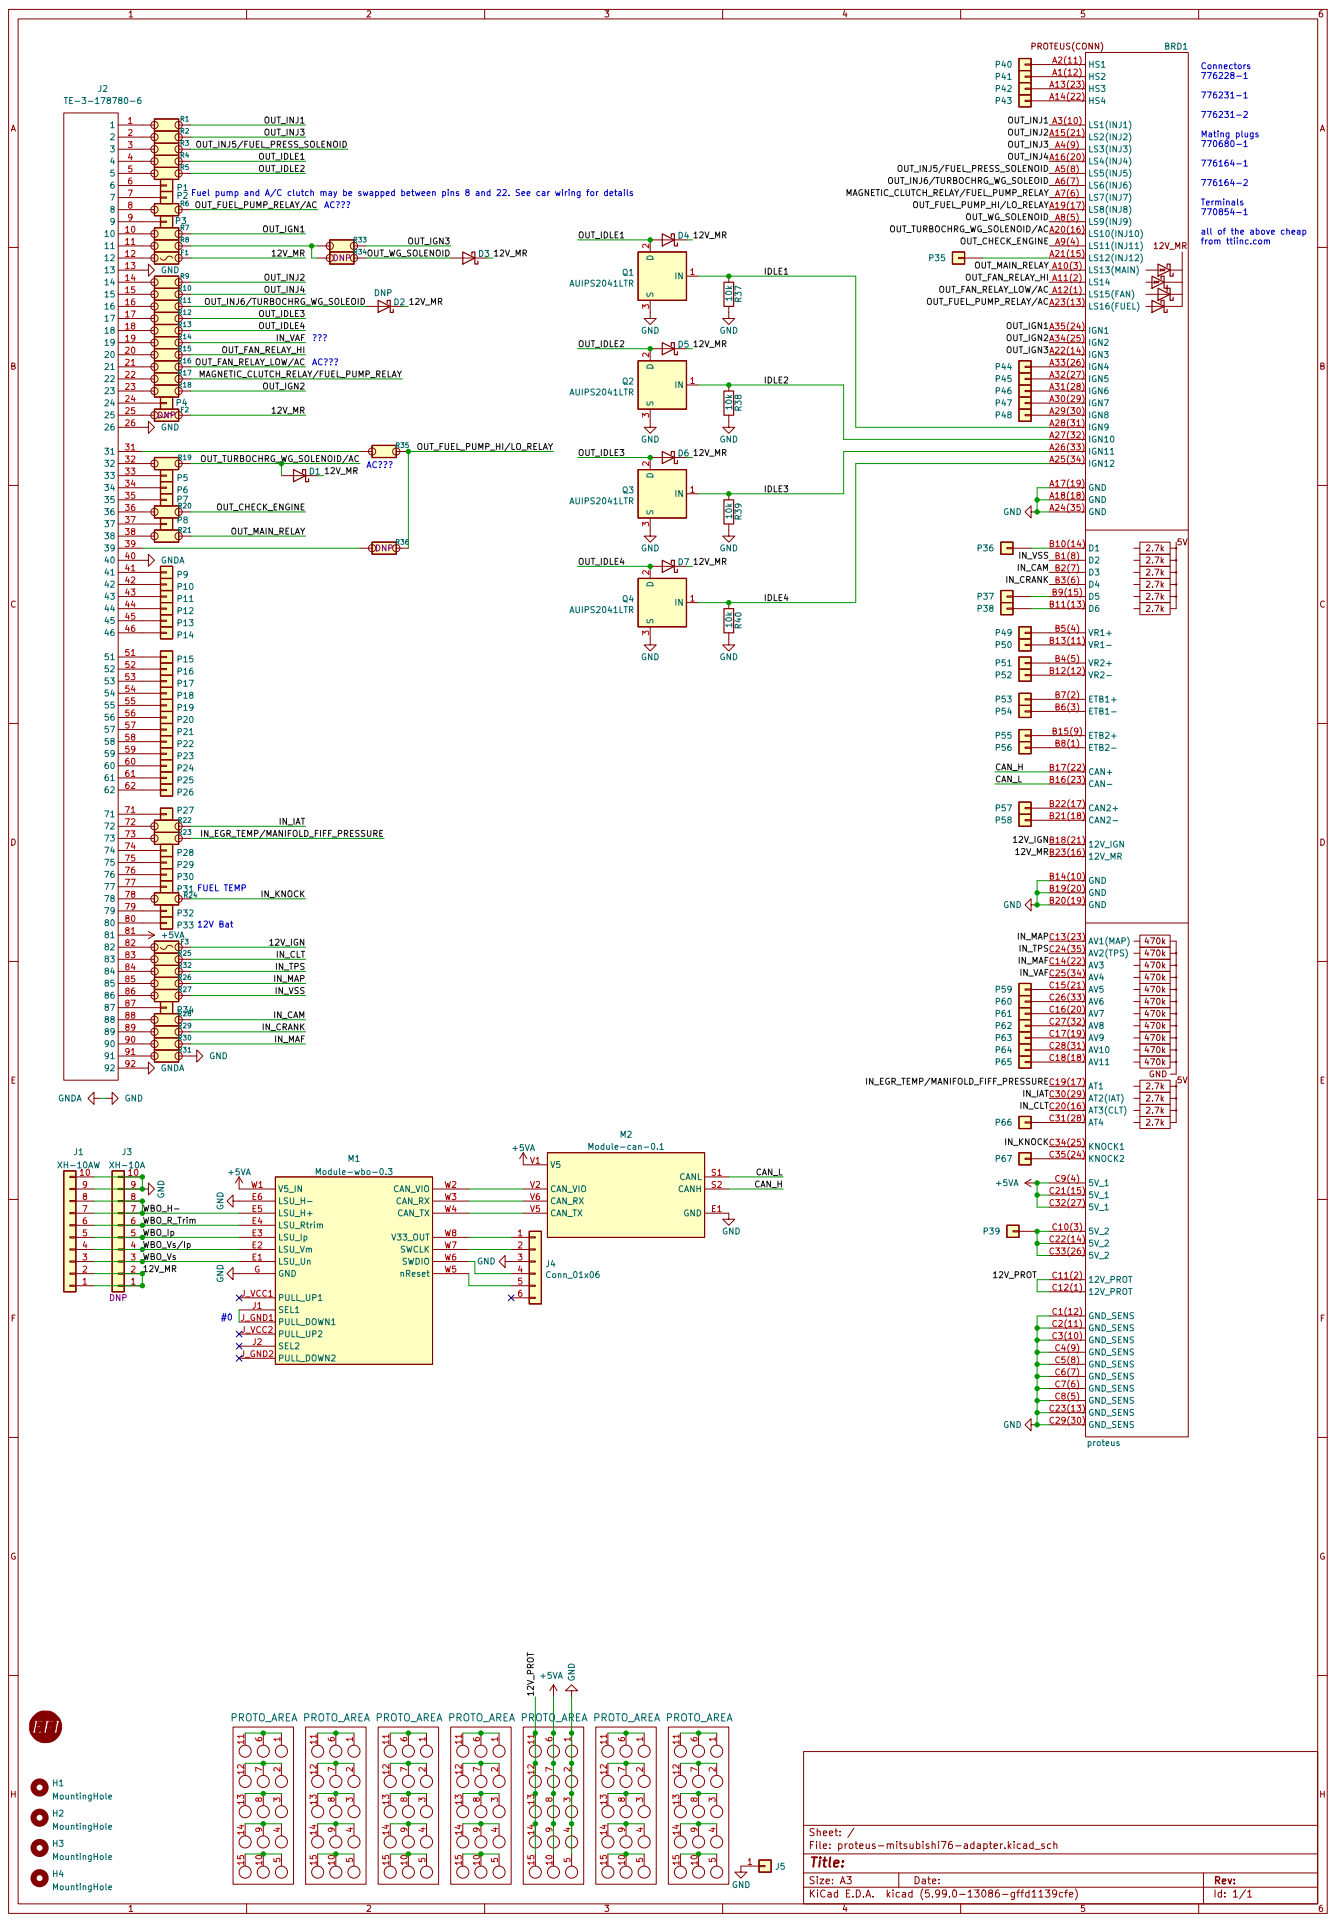
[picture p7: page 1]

AC??? Fuel pump and A/C clutch may be swapped between pins 8 and 22. See car wiring for details ???

all of the above cheap
from ttiinc.com

File: proteus-mitsubishi76-adapter.kicad_sch Sheet: /

1kR600

3.3k R623

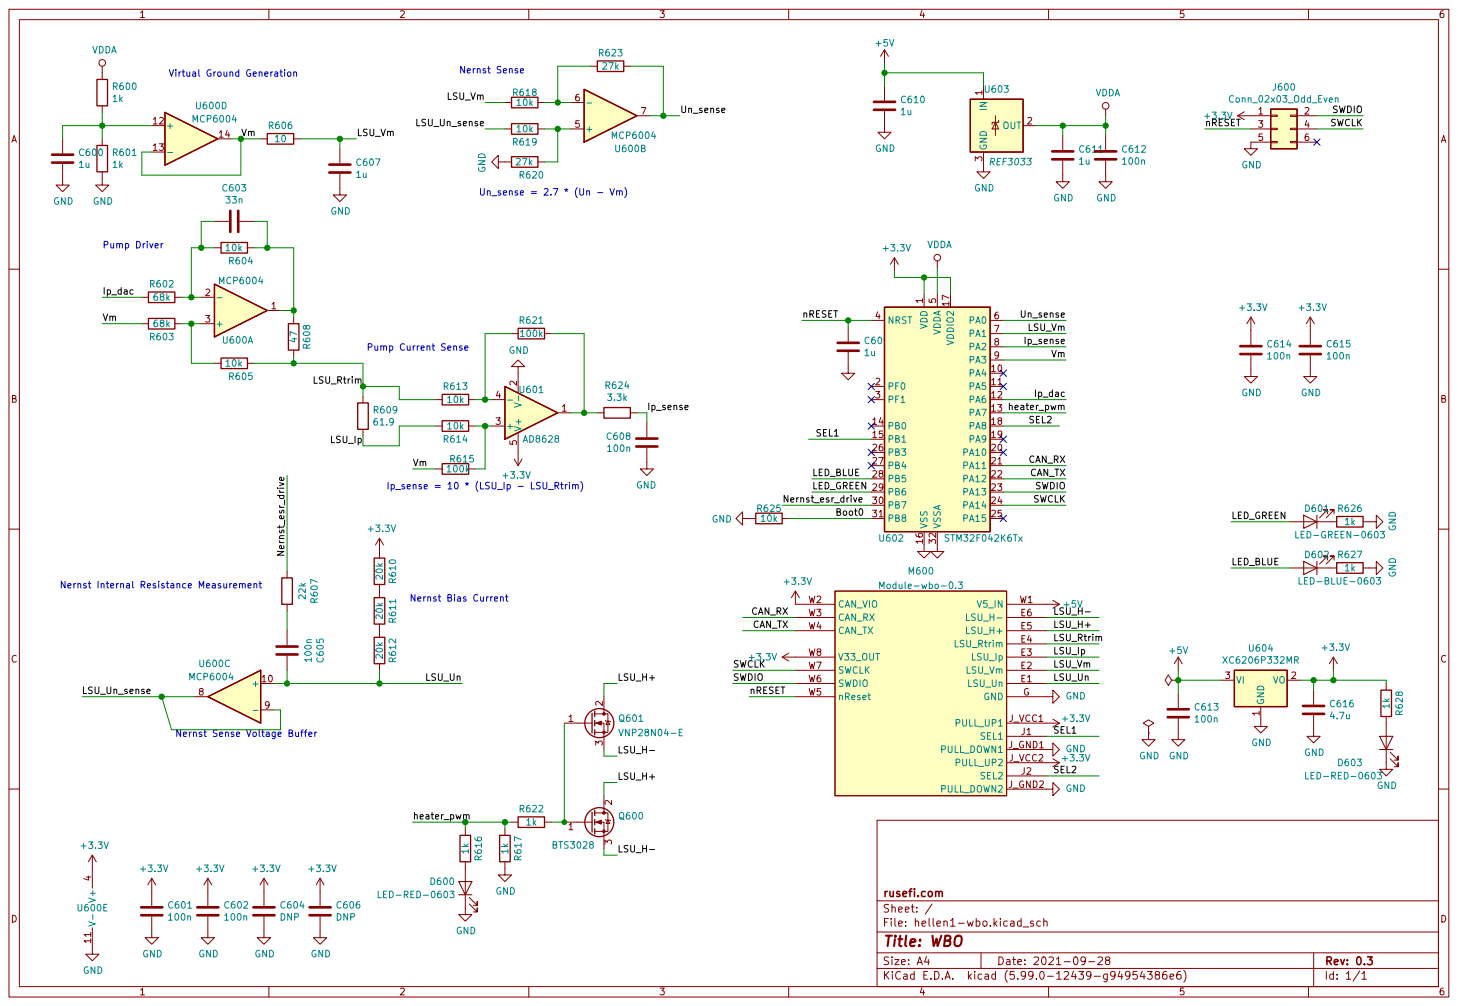
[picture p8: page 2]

Pump Current Sense Nernst Sense

LSU_Vm
Pump Driver Nernst Internal Resistance Measurement

1 VO 2 VI 3 U604 XC6206P332MR GND GND

1 PA4 10 PA5 11 PA6 12 PA7 13 PB0 14 PB1 15 VSS 16 VDDIO2 17 PA8 18 PA9 19 PF0 2 PA10 20 PA11 21 PA12 22 PA13 23 PA14 24 PA15 25 PB3 26 PB4 27 PB5 28 PB6 29 PF1 3 PB7 30 PB8 31 VSSA 32 NRST 4 VDDA

LED-RED-0603 ¹⁰⁰n C⁶⁰⁵ C604 DNP

Nernst Sense Voltage Buffer

1k GND GND R⁶¹⁶ ¹k

File: hellen1-wbo.kicad_sch Sheet: / rusefi.com

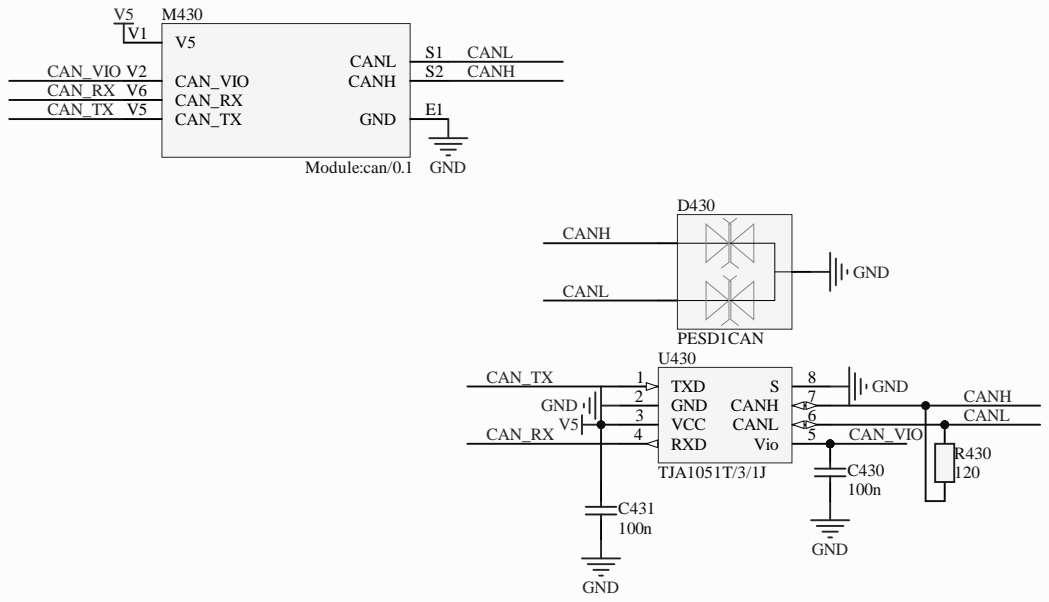
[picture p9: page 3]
andreika; Size:; Author:; Date:; Revision:; Sheet; PESD1CAN; GND; CANH; CANL; TXD 1 GND 2 VCC 3; Vio; 5 RXD 4; 6 CANH; TJA1051T/3/1J; CANH CANL; CAN_TX; CAN_RX; CAN_VIO; CAN_VIO V2; S2 CANL; CAN_TX V5; CAN_RX V6; Module:can/0.1

Hellen-One CAN
Title:

rusEFI EMS
Hellen-One Platform
https://rusefi.com/s/hellen72

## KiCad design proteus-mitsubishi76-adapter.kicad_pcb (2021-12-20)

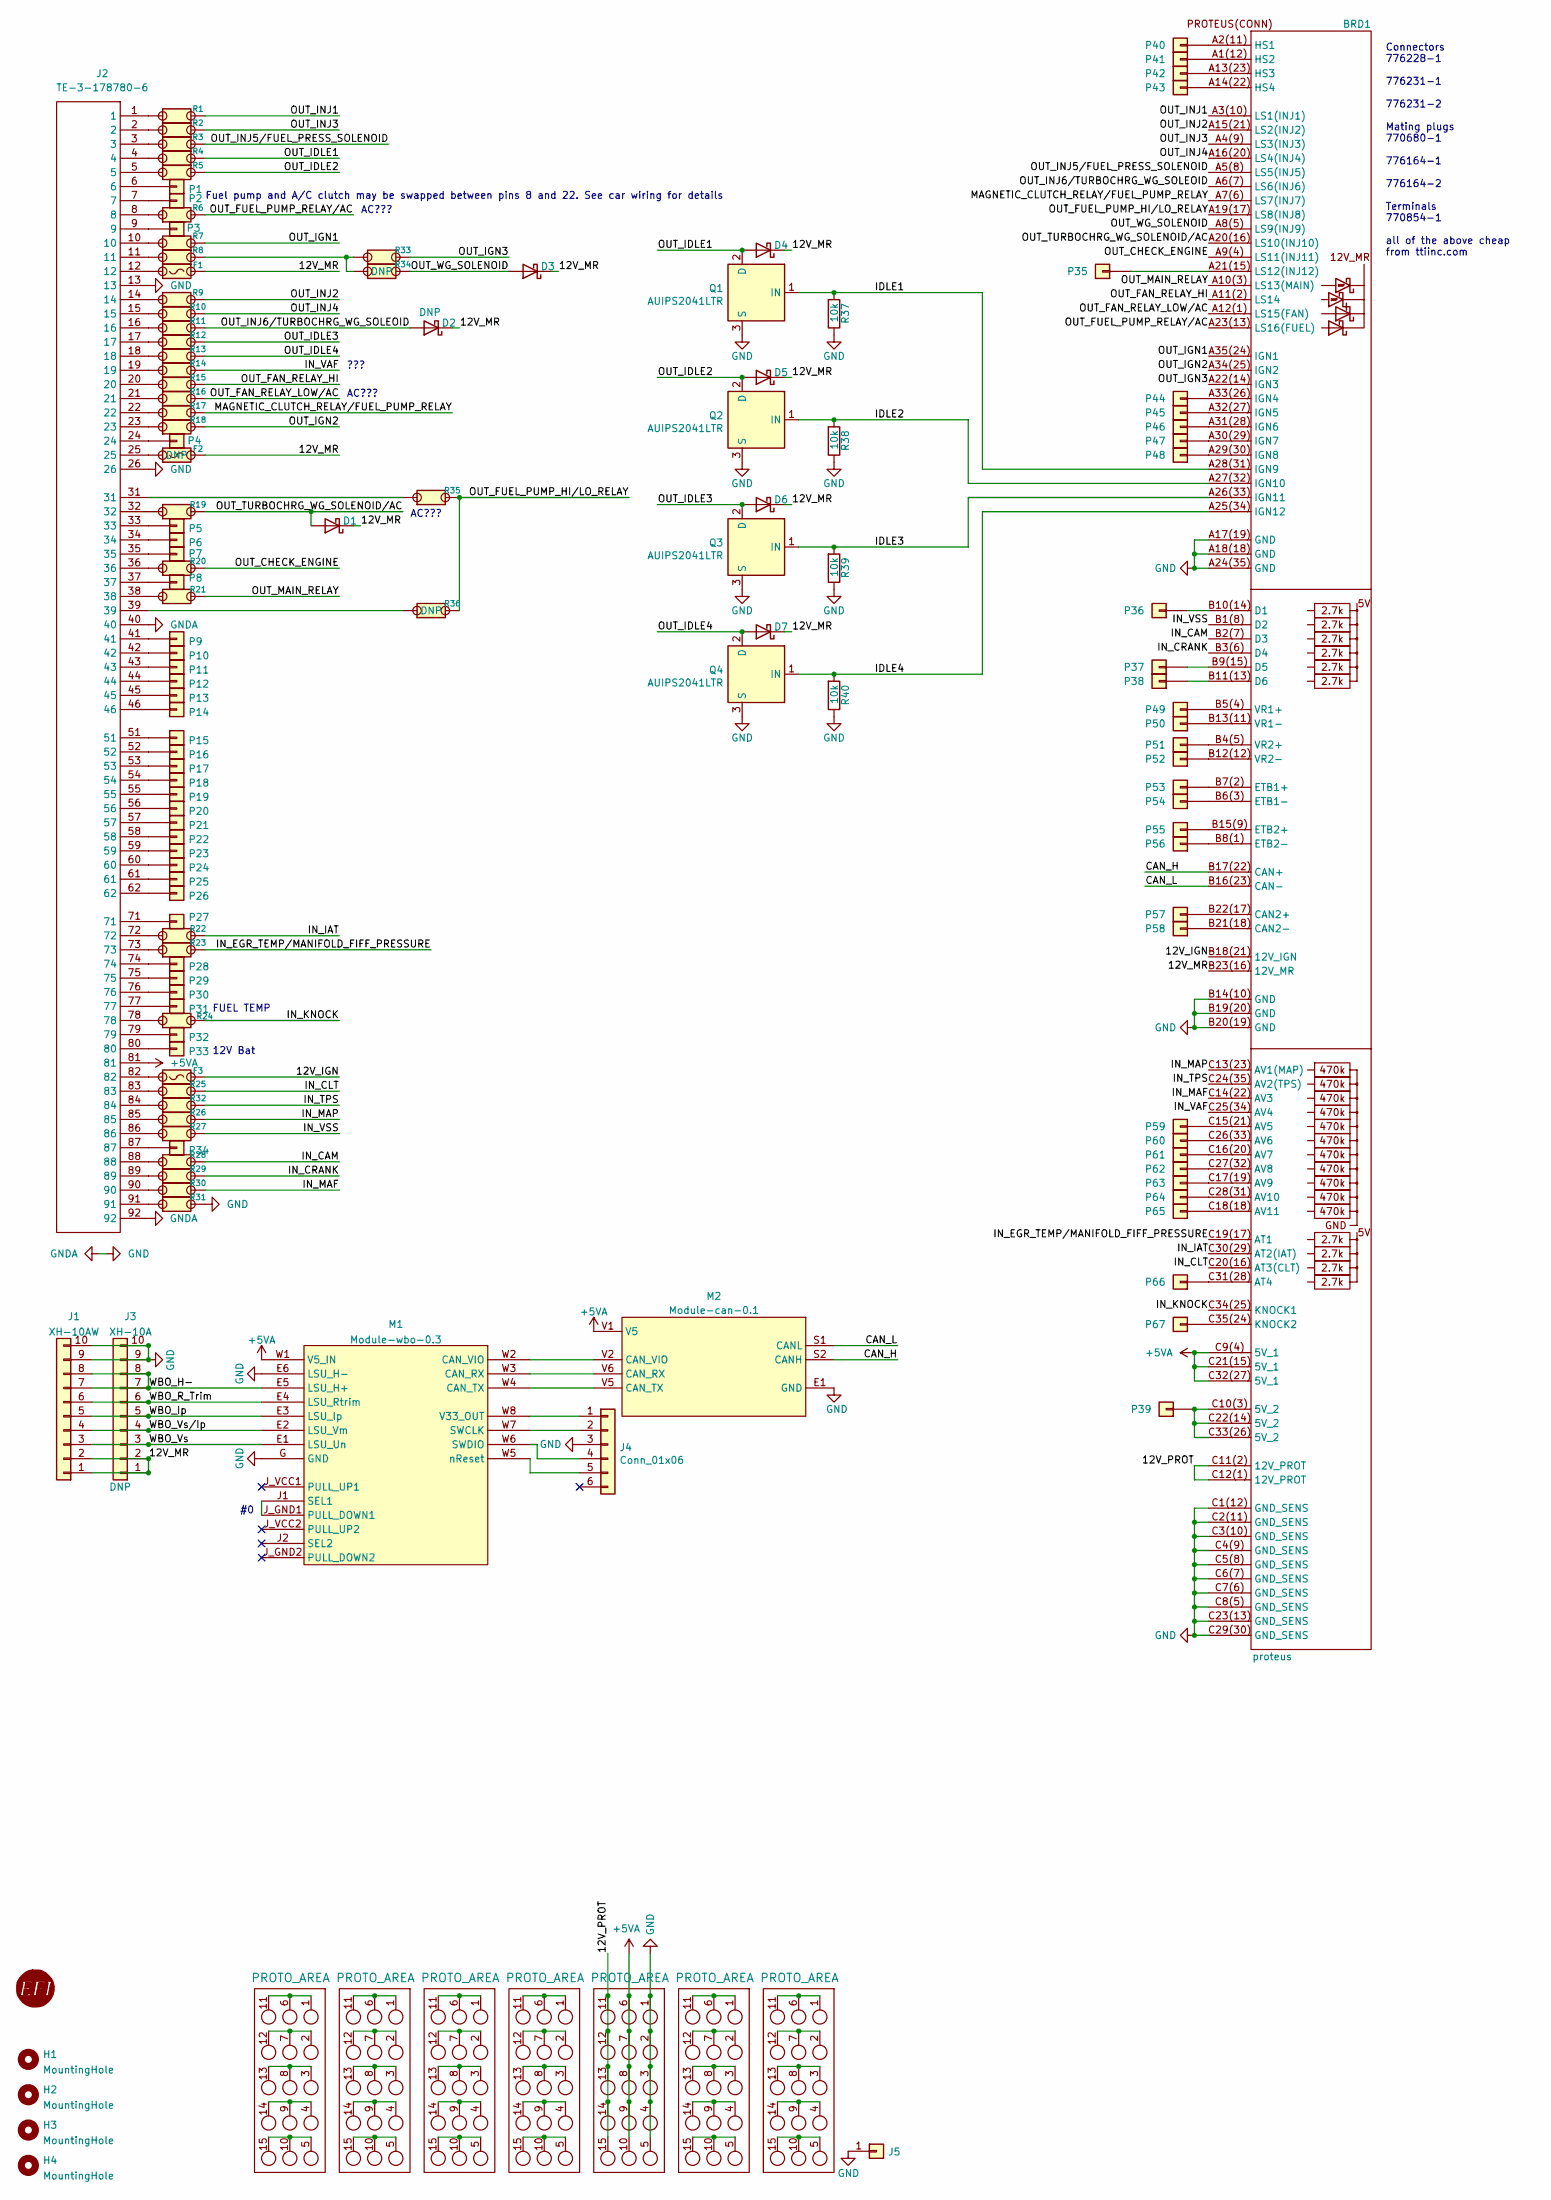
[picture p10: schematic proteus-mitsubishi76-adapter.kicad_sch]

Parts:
BRD1: proteus
D1, D3, D4, D5, D6, D7: D_Schottky; D_SMA; LCSC C8678
D2: DNP; D_SMA; LCSC_ext 0
F1, F3: Fuse-Pad-Pad; PAD-1206-PAD; LCSC C182446
F2: Fuse-Pad-Pad; PAD-1206-PAD
G1: RUSEFI_LOGO; rusefi_logo
G2, G3, G4, G5, G6, G7, G8: PROTO_AREA
H1, H2, H3, H4: MountingHole; MountingHole_5mm_Pad_TopOnly
J1: XH-10AW; JST_XH_S10B-XH-A_1x10_P2.50mm_Horizontal; LCSC C14652
J2: TE-3-178780-6
J3: XH-10A; JST_XH_B10B-XH-A_1x10_P2.50mm_Vertical; LCSC C8885
J4: Conn_01x06; PinHeader_1x06_P2.54mm_Vertical
J5: Conn_01x01; TestPoint_Pad_D4.0mm
M1: Module-wbo-0.3; wbo
M2: Module-can-0.1; can
P1, P2, P3, P4, P5, P6, P7, P8, P9, P10, P11, P12, P13, P14, P15, P16, P17, P18, P19, P20, P21, P22, P23, P24, P25, P26, P27, P28, P29, P30, P31, P32, P33, P34, P35, P36, P37, P38, P39, P40, P41, P42, P43, P44, P45, P46, P47, P48, P49, P50, P51, P52, P53, P54, P55, P56, P57, P58, P59, P60, P61, P62, P63, P64, P65, P66, P67: Pad; PAD-TH
Q1, Q2, Q3, Q4: AUIPS2041LTR; SOT-223; LCSC C113610
R1, R2, R3, R4, R5, R6, R7, R8, R9, R10, R11, R12, R13, R14, R15, R16, R17, R18, R19, R20, R21, R22, R23, R24, R25, R26, R27, R28, R29, R30, R31, R32, R33, R35: Jumper-Pad-Pad; PAD-0805-PAD; LCSC C17477
R34, R36: Jumper-Pad-Pad; PAD-0805-PAD
R37, R38, R39, R40: 10k; R_0402_1005Metric; LCSC C60489

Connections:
+5VA: BRD1.C9(4) (5V_1), BRD1.C21(15) (5V_1), BRD1.C32(27) (5V_1), G6.6, G6.7, G6.8, G6.9, G6.10, J2.81, M1.W1 (V5_IN), M2.V1 (V5)
/12V_IGN: BRD1.B18(21) (12V_IGN), F3.2
/12V_MR: BRD1.B23(16) (12V_MR), D1.1 (K), D2.1 (K), D3.1 (K), D4.1 (K), D5.1 (K), D6.1 (K), D7.1 (K), F1.2, F2.2, J1.1, J1.2, J3.1, J3.2
/12V_PROT: BRD1.C11(2) (12V_PROT), BRD1.C12(1) (12V_PROT), G6.11, G6.12, G6.13, G6.14, G6.15
/CAN_H: BRD1.B17(22) (CAN+), M2.S2 (CANH)
/CAN_L: BRD1.B16(23) (CAN-), M2.S1 (CANL)
/IDLE1: BRD1.A28(31) (IGN9), Q1.1 (IN), R37.2
/IDLE2: BRD1.A27(32) (IGN10), Q2.1 (IN), R38.2
/IDLE3: BRD1.A26(33) (IGN11), Q3.1 (IN), R39.2
/IDLE4: BRD1.A25(34) (IGN12), Q4.1 (IN), R40.2
/IN_CAM: BRD1.B2(7) (D3), R28.2
/IN_CLT: BRD1.C20(16) (AT3(CLT)), R25.2
/IN_CRANK: BRD1.B3(6) (D4), R29.2
/IN_EGR_TEMP/MANIFOLD_FIFF_PRESSURE: BRD1.C19(17) (AT1), R23.2
/IN_IAT: BRD1.C30(29) (AT2(IAT)), R22.2
/IN_KNOCK: BRD1.C34(25) (KNOCK1), R24.2
/IN_MAF: BRD1.C14(22) (AV3), R30.2
/IN_MAP: BRD1.C13(23) (AV1(MAP)), R26.2
/IN_TPS: BRD1.C24(35) (AV2(TPS)), R32.2
/IN_VAF: BRD1.C25(34) (AV4), R14.2
/IN_VSS: BRD1.B1(8) (D2), R27.2
/MAGNETIC_CLUTCH_RELAY/FUEL_PUMP_RELAY: BRD1.A7(6) (LS7(INJ7)), R17.2
/OUT_CHECK_ENGINE: BRD1.A9(4) (LS11(INJ11)), R20.2
/OUT_FAN_RELAY_HI: BRD1.A11(2) (LS14), R15.2
/OUT_FAN_RELAY_LOW/AC: BRD1.A12(1) (LS15(FAN)), R16.2
/OUT_FUEL_PUMP_HI/LO_RELAY: BRD1.A19(17) (LS8(INJ8)), R35.2, R36.2
/OUT_FUEL_PUMP_RELAY/AC: BRD1.A23(13) (LS16(FUEL)), R6.2
/OUT_IDLE1: D4.2 (A), Q1.2 (D), R4.2
/OUT_IDLE2: D5.2 (A), Q2.2 (D), R5.2
/OUT_IDLE3: D6.2 (A), Q3.2 (D), R12.2
/OUT_IDLE4: D7.2 (A), Q4.2 (D), R13.2
/OUT_IGN1: BRD1.A35(24) (IGN1), R7.2
/OUT_IGN2: BRD1.A34(25) (IGN2), R18.2
/OUT_IGN3: BRD1.A22(14) (IGN3), R33.2
/OUT_INJ1: BRD1.A3(10) (LS1(INJ1)), R1.2
/OUT_INJ2: BRD1.A15(21) (LS2(INJ2)), R9.2
/OUT_INJ3: BRD1.A4(9) (LS3(INJ3)), R2.2
/OUT_INJ4: BRD1.A16(20) (LS4(INJ4)), R10.2
/OUT_INJ5/FUEL_PRESS_SOLENOID: BRD1.A5(8) (LS5(INJ5)), R3.2
/OUT_INJ6/TURBOCHRG_WG_SOLEOID: BRD1.A6(7) (LS6(INJ6)), D2.2 (A), R11.2
/OUT_MAIN_RELAY: BRD1.A10(3) (LS13(MAIN)), R21.2
/OUT_TURBOCHRG_WG_SOLENOID/AC: BRD1.A20(16) (LS10(INJ10)), D1.2 (A), R19.2
/OUT_WG_SOLENOID: BRD1.A8(5) (LS9(INJ9)), D3.2 (A), R34.2
/WBO_H-: J1.7, J1.8, J3.7, J3.8, M1.E5 (LSU_H+)
/WBO_Ip: J1.5, J3.5, M1.E3 (LSU_Ip)
/WBO_R_Trim: J1.6, J3.6, M1.E4 (LSU_Rtrim)
/WBO_Vs: J1.3, J3.3, M1.E1 (LSU_Un)
/WBO_Vs/Ip: J1.4, J3.4, M1.E2 (LSU_Vm)
GND: BRD1.A17(19) (GND), BRD1.A18(18) (GND), BRD1.A24(35) (GND), BRD1.B14(10) (GND), BRD1.B19(20) (GND), BRD1.B20(19) (GND), BRD1.C1(12) (GND_SENS), BRD1.C2(11) (GND_SENS), BRD1.C3(10) (GND_SENS), BRD1.C4(9) (GND_SENS), BRD1.C5(8) (GND_SENS), BRD1.C6(7) (GND_SENS), BRD1.C7(6) (GND_SENS), BRD1.C8(5) (GND_SENS), BRD1.C23(13) (GND_SENS), BRD1.C29(30) (GND_SENS), G6.1, G6.2, G6.3, G6.4, G6.5, J1.9, J1.10, J2.13, J2.26, J2.40, J2.92, J3.9, J3.10, J4.3, J5.1, M1.E6 (LSU_H-), M1.G (GND), M2.E1 (GND), Q1.3 (S), Q2.3 (S), Q3.3 (S), Q4.3 (S), R31.2, R37.1, R38.1, R39.1, R40.1
unnamed: BRD1.A1(12) (HS2), P41.1
unnamed: BRD1.A2(11) (HS1), P40.1
unnamed: BRD1.A13(23) (HS3), P42.1
unnamed: BRD1.A14(22) (HS4), P43.1
unnamed: BRD1.A21(15) (LS12(INJ12)), P35.1
unnamed: BRD1.A29(30) (IGN8), P48.1
unnamed: BRD1.A30(29) (IGN7), P47.1
unnamed: BRD1.A31(28) (IGN6), P46.1
unnamed: BRD1.A32(27) (IGN5), P45.1
unnamed: BRD1.A33(26) (IGN4), P44.1
unnamed: BRD1.B4(5) (VR2+), P51.1
unnamed: BRD1.B5(4) (VR1+), P49.1
unnamed: BRD1.B6(3) (ETB1-), P54.1
unnamed: BRD1.B7(2) (ETB1+), P53.1
unnamed: BRD1.B8(1) (ETB2-), P56.1
unnamed: BRD1.B9(15) (D5), P37.1
unnamed: BRD1.B10(14) (D1), P36.1
unnamed: BRD1.B11(13) (D6), P38.1
unnamed: BRD1.B12(12) (VR2-), P52.1
unnamed: BRD1.B13(11) (VR1-), P50.1
unnamed: BRD1.B15(9) (ETB2+), P55.1
unnamed: BRD1.B21(18) (CAN2-), P58.1
unnamed: BRD1.B22(17) (CAN2+), P57.1
unnamed: BRD1.C10(3) (5V_2), BRD1.C22(14) (5V_2), BRD1.C33(26) (5V_2), P39.1
unnamed: BRD1.C15(21) (AV5), P59.1
unnamed: BRD1.C16(20) (AV7), P61.1
unnamed: BRD1.C17(19) (AV9), P63.1
unnamed: BRD1.C18(18) (AV11), P65.1
unnamed: BRD1.C26(33) (AV6), P60.1
unnamed: BRD1.C27(32) (AV8), P62.1
unnamed: BRD1.C28(31) (AV10), P64.1
unnamed: BRD1.C31(28) (AT4), P66.1
unnamed: BRD1.C35(24) (KNOCK2), P67.1
unnamed: F1.1, J2.12
unnamed: F2.1, J2.25
unnamed: F3.1, J2.82
unnamed: G2.1, G2.6, G2.11
unnamed: G2.5, G2.10, G2.15
unnamed: G2.2, G2.7, G2.12
unnamed: G2.3, G2.8, G2.13
unnamed: G2.4, G2.9, G2.14
unnamed: G3.1, G3.6, G3.11
unnamed: G3.5, G3.10, G3.15
unnamed: G3.2, G3.7, G3.12
unnamed: G3.3, G3.8, G3.13
unnamed: G3.4, G3.9, G3.14
unnamed: G4.1, G4.6, G4.11
unnamed: G4.5, G4.10, G4.15
unnamed: G4.2, G4.7, G4.12
unnamed: G4.3, G4.8, G4.13
unnamed: G4.4, G4.9, G4.14
unnamed: G5.1, G5.6, G5.11
unnamed: G5.5, G5.10, G5.15
unnamed: G5.2, G5.7, G5.12
unnamed: G5.3, G5.8, G5.13
unnamed: G5.4, G5.9, G5.14
unnamed: G7.1, G7.6, G7.11
unnamed: G7.5, G7.10, G7.15
unnamed: G7.2, G7.7, G7.12
unnamed: G7.3, G7.8, G7.13
unnamed: G7.4, G7.9, G7.14
unnamed: G8.1, G8.6, G8.11
unnamed: G8.5, G8.10, G8.15
unnamed: G8.2, G8.7, G8.12
unnamed: G8.3, G8.8, G8.13
unnamed: G8.4, G8.9, G8.14
unnamed: J2.1, R1.1
unnamed: J2.2, R2.1
unnamed: J2.3, R3.1
unnamed: J2.4, R4.1
unnamed: J2.5, R5.1
unnamed: J2.6, P1.1
unnamed: J2.7, P2.1
unnamed: J2.8, R6.1
unnamed: J2.9, P3.1
unnamed: J2.10, R7.1
unnamed: J2.11, R8.1
unnamed: J2.14, R9.1
unnamed: J2.15, R10.1
unnamed: J2.16, R11.1
unnamed: J2.17, R12.1
unnamed: J2.18, R13.1
unnamed: J2.19, R14.1
unnamed: J2.20, R15.1
unnamed: J2.21, R16.1
unnamed: J2.22, R17.1
unnamed: J2.23, R18.1
unnamed: J2.24, P4.1
unnamed: J2.31, R35.1
unnamed: J2.32, R19.1
unnamed: J2.33, P5.1
unnamed: J2.34, P6.1
unnamed: J2.35, P7.1
unnamed: J2.36, R20.1
unnamed: J2.37, P8.1
unnamed: J2.38, R21.1
unnamed: J2.39, R36.1
unnamed: J2.41, P9.1
unnamed: J2.42, P10.1
unnamed: J2.43, P11.1
unnamed: J2.44, P12.1
unnamed: J2.45, P13.1
unnamed: J2.46, P14.1
unnamed: J2.51, P15.1
unnamed: J2.52, P16.1
unnamed: J2.53, P17.1
unnamed: J2.54, P18.1
unnamed: J2.55, P19.1
unnamed: J2.56, P20.1
unnamed: J2.57, P21.1
unnamed: J2.58, P22.1
unnamed: J2.59, P23.1
unnamed: J2.60, P24.1
unnamed: J2.61, P25.1
unnamed: J2.62, P26.1
unnamed: J2.71, P27.1
unnamed: J2.72, R22.1
unnamed: J2.73, R23.1
unnamed: J2.74, P28.1
unnamed: J2.75, P29.1
unnamed: J2.76, P30.1
unnamed: J2.77, P31.1
unnamed: J2.78, R24.1
unnamed: J2.79, P32.1
unnamed: J2.80, P33.1
unnamed: J2.83, R25.1
unnamed: J2.84, R32.1
unnamed: J2.85, R26.1
unnamed: J2.86, R27.1
unnamed: J2.87, P34.1
unnamed: J2.88, R28.1
unnamed: J2.89, R29.1
unnamed: J2.90, R30.1
unnamed: J2.91, R31.1
unnamed: J4.1, M1.W8 (V33_OUT)
unnamed: J4.2, M1.W7 (SWCLK)
unnamed: J4.4, M1.W6 (SWDIO)
unnamed: J4.5, M1.W5 (nReset)
unnamed: M1.J1 (SEL1), M1.J_GND1 (PULL_DOWN1)
unnamed: M1.W2 (CAN_VIO), M2.V2 (CAN_VIO)
unnamed: M1.W3 (CAN_RX), M2.V6 (CAN_RX)
unnamed: M1.W4 (CAN_TX), M2.V5 (CAN_TX)
unnamed: R8.2, R33.1, R34.1

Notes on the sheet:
FUEL TEMP
AC???
???
Connectors 776228-1 776231-1 776231-2 Mating plugs 770680-1 776164-1 776164-2 Terminals 770854-1 all of the above cheap from ttiinc.com
Fuel pump and A/C clutch may be swapped between pins 8 and 22. See car wiring for details
12V Bat

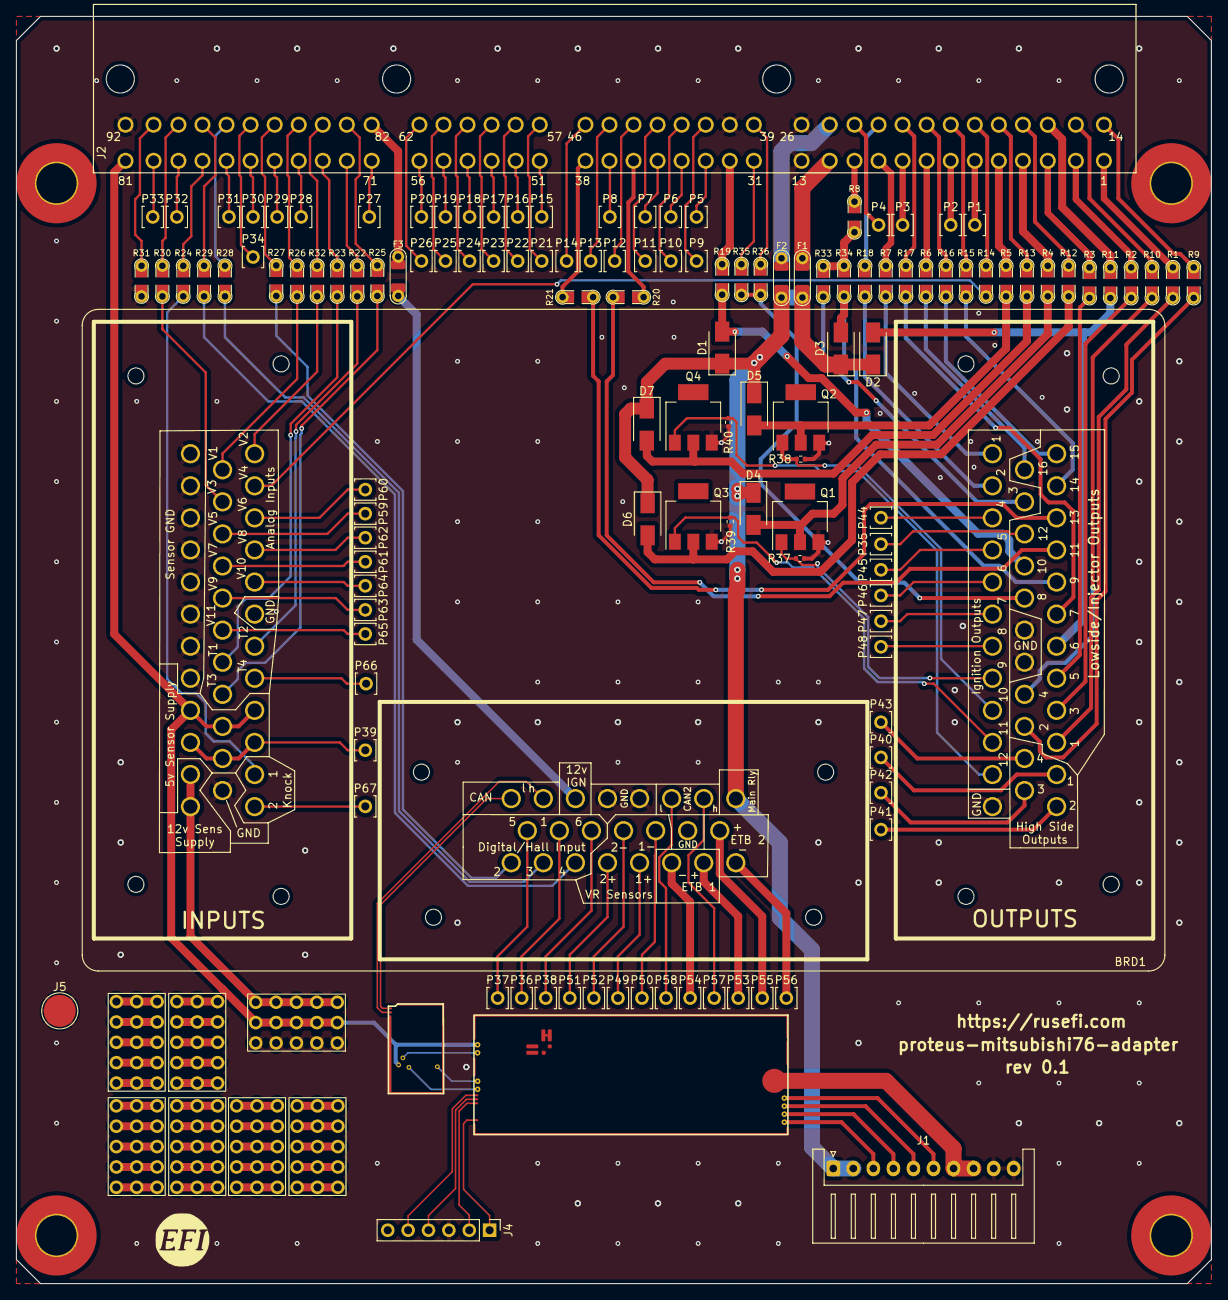
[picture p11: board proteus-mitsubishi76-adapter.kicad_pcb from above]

Board: 2 copper layers, 149.0 x 158.0 mm, 140 parts (0 on the bottom side), 192 nets.

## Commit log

2021-10-25 76 pin footprint
2021-11-05 board outline
    [proteus-mitsubishi76-adapter.kicad_pcb, proteus-mitsubishi76-adapter.kicad_sch]
2021-12-06 Upd sch
    [proteus-mitsubishi76-adapter.kicad_sch]
2021-12-08 Starter pin, 8/22 pins note
    [proteus-mitsubishi76-adapter.kicad_sch]
2021-12-20 Board routing
    [proteus-mitsubishi76-adapter.kicad_pcb]
2021-12-27 Add files via upload
    Pcb corrections.
2021-12-29 Fab preview
    [-mitsubishi76-adapter-BOM.csv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]
